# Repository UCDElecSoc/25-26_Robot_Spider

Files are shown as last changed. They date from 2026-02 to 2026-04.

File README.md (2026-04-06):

🕷️ Spider Bot: "LOOK MA, IM JUST LIKE SPIDERMAN!"

Sprider Bot is an open-source, 3D-printed hexapod robot. Built on the ESP32 platform, it features 24 servos and supports remote control via Bluetooth/Radio with a built in camera.

🎥 [Pics](https://github.com/UCDElecSoc/25-26_Robot_Spider/tree/main/Media) | 📁 [Download STL Files](https://github.com/UCDElecSoc/25-26_Robot_Spider/tree/main/Spider%20STLs) | 📖 [Read code](https://github.com/UCDElecSoc/25-26_Robot_Spider/tree/main/Spider_Robot)

🚀 Key Features

24 Servos: 3 joints per leg (Coxa, Femur, Tibia) for fluid, spider-like motion.

A camera: to break several international privacy laws

Spider like motion: to terrorise arachnophobes

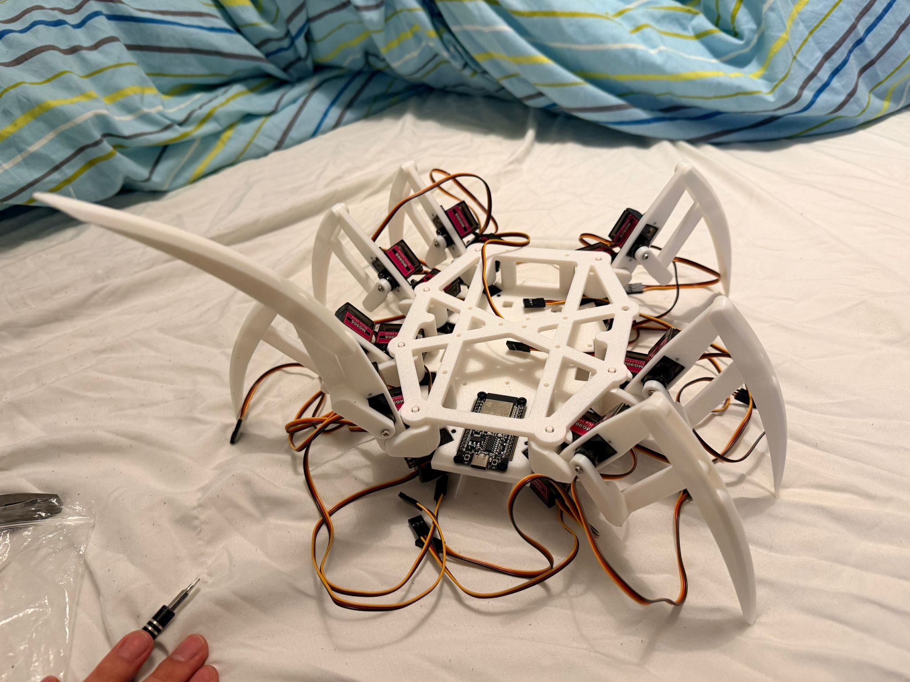
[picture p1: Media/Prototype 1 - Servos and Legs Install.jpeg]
Prototype 1 Image


🛠️ Hardware Requirements

| Component | Quantity | Description |
| :--- | :--- | :--- |
| **Microcontroller** | 1 | ESP32 S3 with Camera |
| **Servo Motors** | 24 | MG90S (Metal Gear) |
| **Servo Driver** | 2 | PCA9685 16-Channel PWM Driver |
| **Power Supply** | 4 | 18650 Cell Battery |
| **Power Regulator** | 1 | 3A 5V BEC |
| **Body** | 1 | 3D Printed Chassis (PETG) |

Open your browser to http://172.20.10.11/ to access the camera, change the password for your own hotspot.
Connect a BTLE or BLE controller to the ESP32 to control the robot

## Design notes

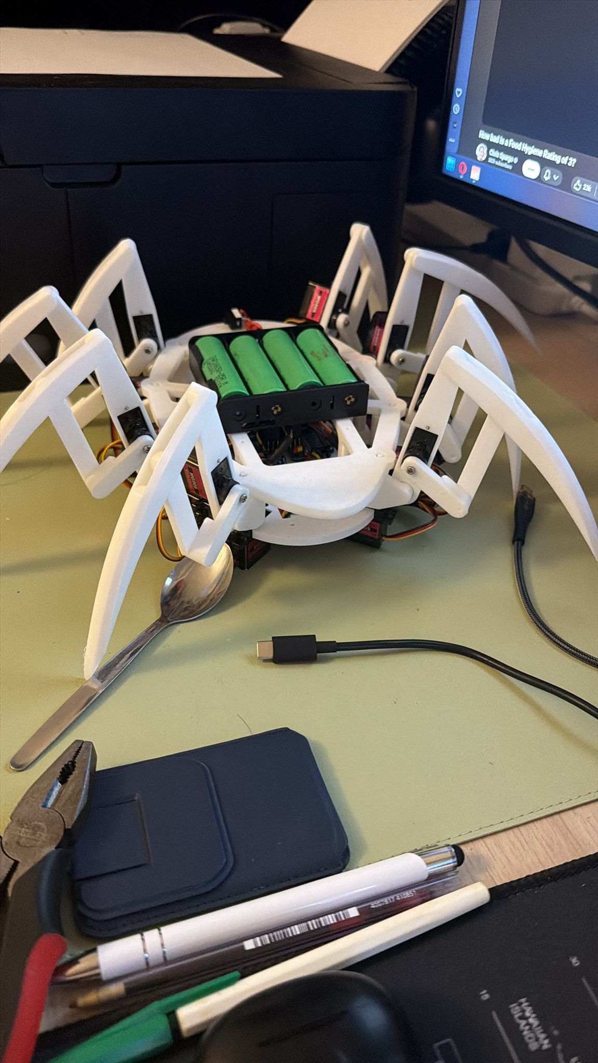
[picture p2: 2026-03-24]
Media/Final Design- Coding time!.jpeg

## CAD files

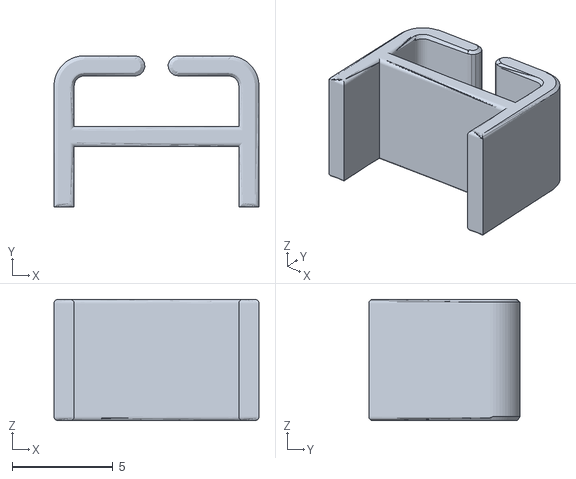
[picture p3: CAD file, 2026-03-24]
Spider STLs/Misc - Cable Clip.stl
10.2 x 7.50 x 6.00

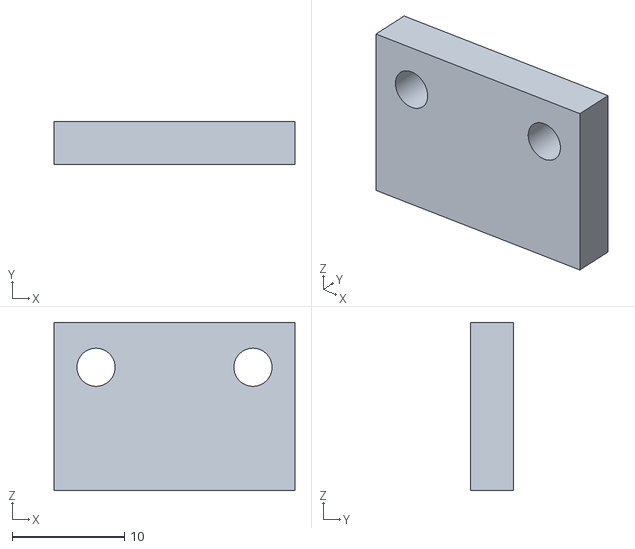
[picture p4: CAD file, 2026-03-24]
Spider STLs/Misc - Camera Esp Holder.stl
21.5 x 3.80 x 15.0

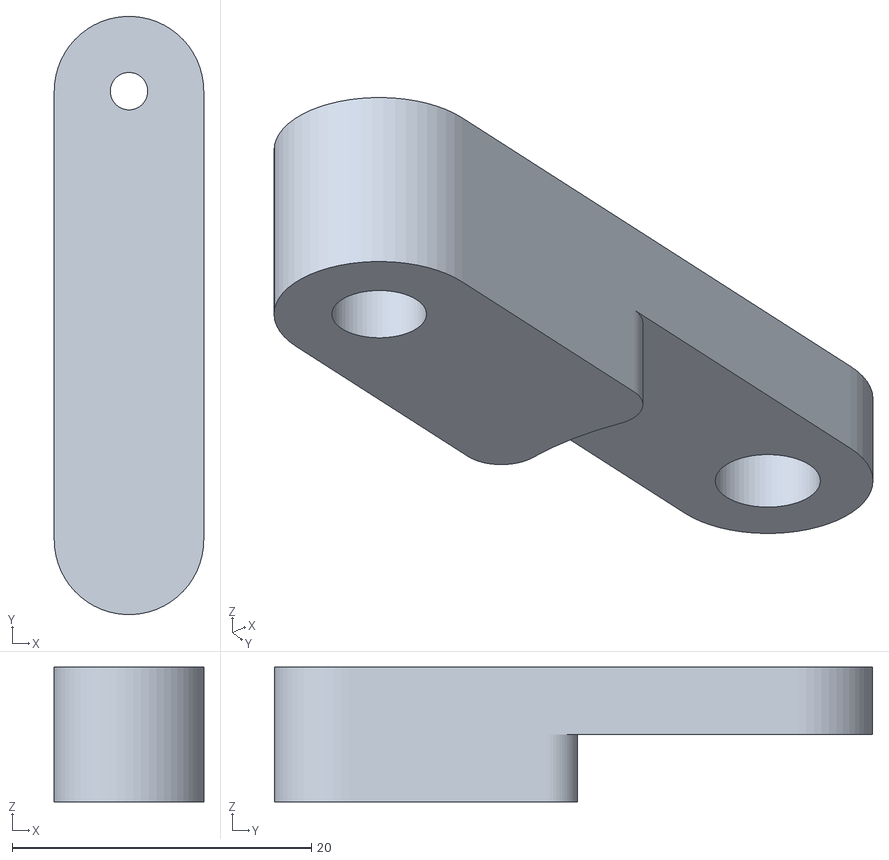
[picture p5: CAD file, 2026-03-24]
Spider STLs/Leg - Short Arm.stl
10.0 x 40.0 x 9.00

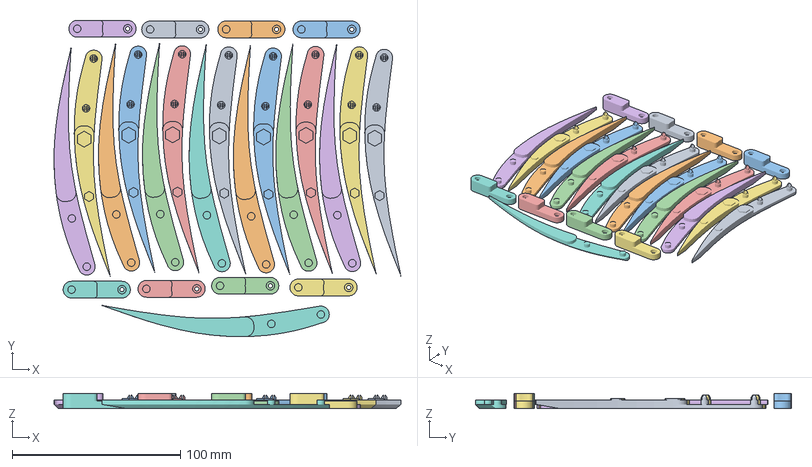
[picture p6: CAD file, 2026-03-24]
Spider STLs/RePrint.3mf
206.5 x 188.3 x 9.00 mm
Leg - Short Arm.stl x 8
Leg - Leg.stl x 16

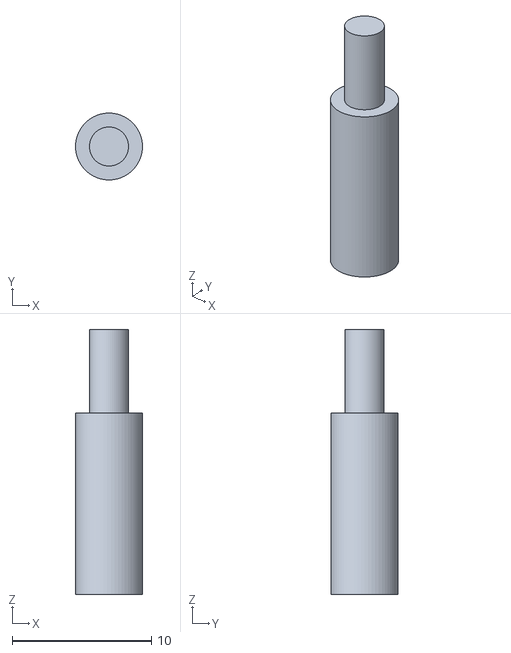
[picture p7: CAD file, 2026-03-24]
Spider STLs/Leg - Base Plug.stl
4.80 x 4.79 x 19.0

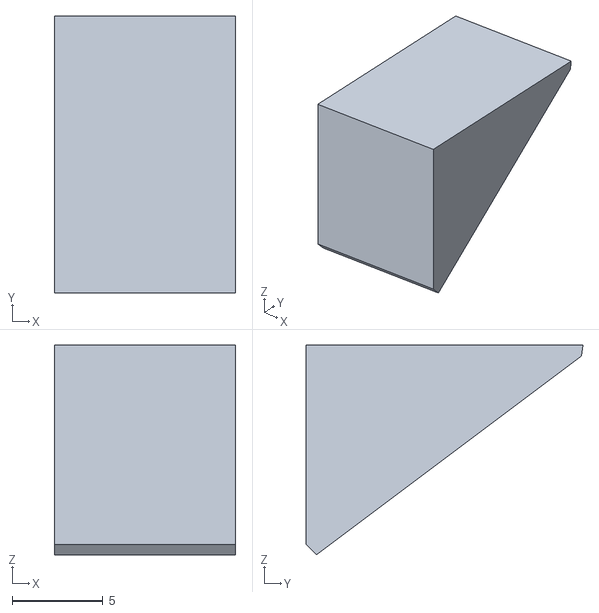
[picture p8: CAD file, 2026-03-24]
Spider STLs/Misc - Camera Stand.stl
10.0 x 15.3 x 11.6

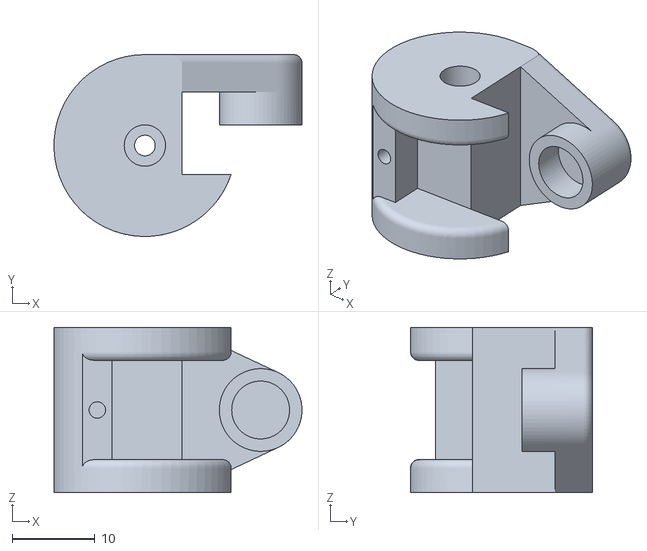
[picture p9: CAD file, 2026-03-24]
Spider STLs/Leg - Base.stl
30.0 x 22.0 x 20.0

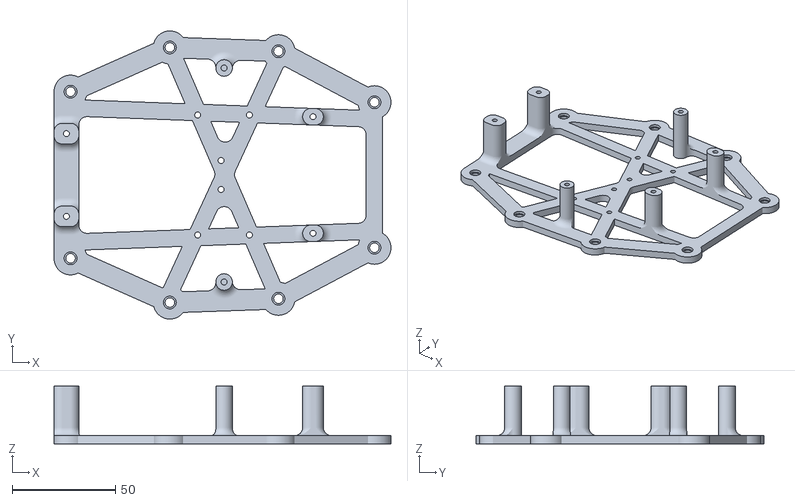
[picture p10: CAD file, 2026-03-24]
Spider STLs/Body - Upper Frame.stl
162.9 x 139.3 x 28.0

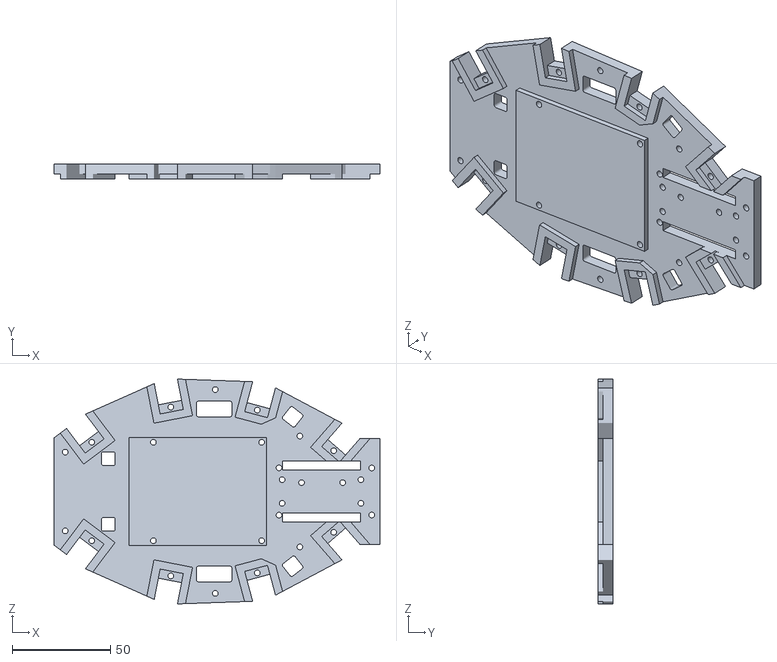
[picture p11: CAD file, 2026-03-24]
Spider STLs/Body - Lower Frame.stl
165.6 x 7.50 x 114.2

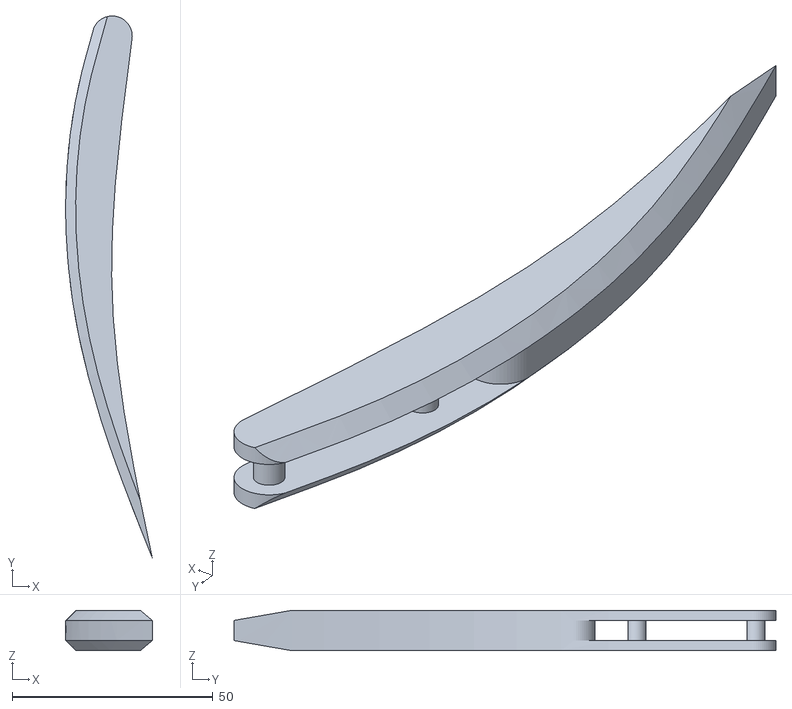
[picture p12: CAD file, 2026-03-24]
Spider STLs/Leg - Leg.stl
21.6 x 135.0 x 10.0

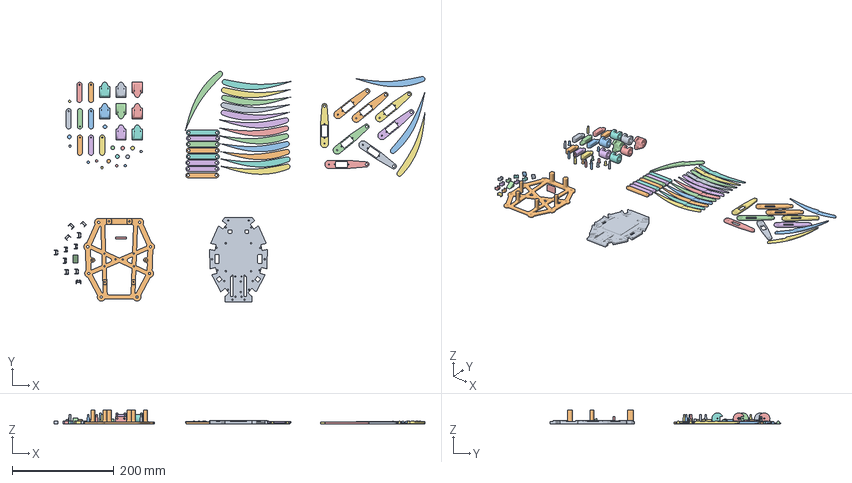
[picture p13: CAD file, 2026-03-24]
Spider STLs/Spider Print.3mf
729.8 x 453.6 x 28.0 mm
Body - Lower Frame.stl
Body - Upper Frame.stl
Leg - Leg.stl x 16
Misc - Camera Stand.stl
Leg - Base.stl x 8
Misc - Cable Clip.stl x 11
Leg - Thigh.stl x 8
Leg - Short Arm.stl x 8
Leg - Short Arm Plug.stl x 8
Leg - Long Arm.stl x 8
Leg - Base Plug.stl x 8
Misc - Camera Esp Holder.stl

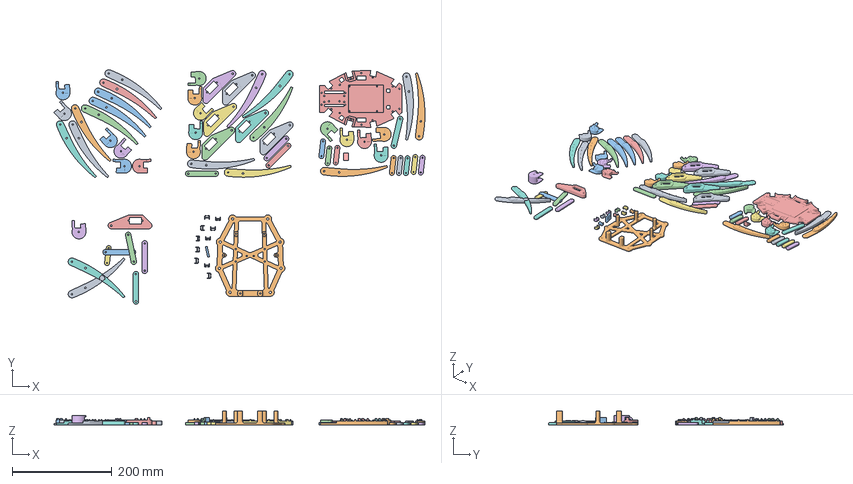
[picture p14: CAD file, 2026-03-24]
Spider STLs/this.3mf
742.4 x 469.3 x 28.0 mm
Spider Leg 0611 - Lower Leg.stl x 16
reinforcementï¼_ bearing frame-2.stl
body concept parts - camera esp stand.stl
Spider Leg 0611 - Lower Beam.stl x 8
body concept parts - Cable clip.stl x 10
body concept parts - body.stl
Spider Leg 0611 - Leg Base.stl x 16
Spider Leg 0611 - Upper Leg.stl x 7
body concept parts - camera stand.stl
Spider Leg 0611 - Upper Beam - Upper Beam.stl x 8
Leg - Leg Base.stl
Leg - Upper Beam.stl
Leg - Lower Leg.stl x 2

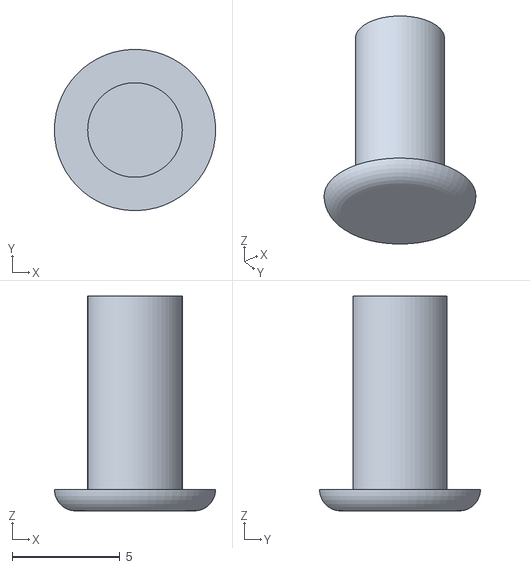
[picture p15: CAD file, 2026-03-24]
Spider STLs/Leg - Short Arm Plug.stl
7.50 x 7.49 x 10.0

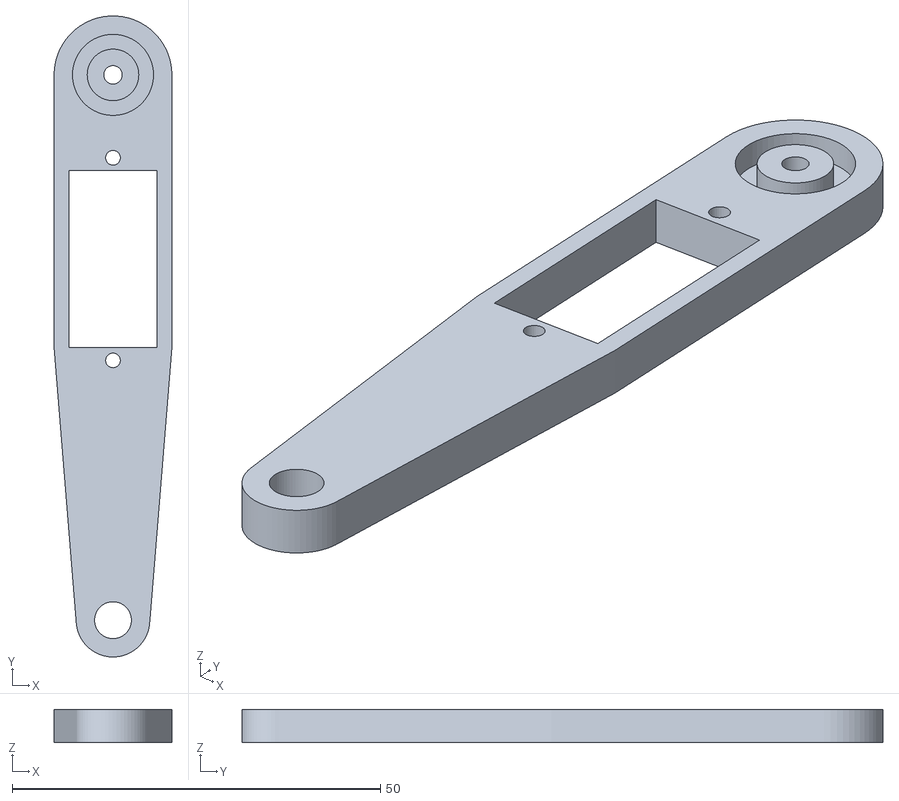
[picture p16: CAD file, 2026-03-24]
Spider STLs/Leg - Thigh.stl
16.0 x 87.0 x 4.50

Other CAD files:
Spider STLs/Leg - Long Arm.stl
Spider STLs/Old Leg/Leg - Upper Leg.stl
Spider STLs/Old Leg/Leg - Upper Beam.stl
Spider STLs/Old Leg/Leg - Lower Beam.stl
Spider STLs/Old Leg/Leg - Leg Base.stl
Spider STLs/Old Leg/Leg - Lower Leg.stl

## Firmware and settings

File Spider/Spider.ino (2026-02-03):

#include <Wire.h>
#include <Adafruit_PWMServoDriver.h>

// Create two PCA9685 objects with different I2C addresses
Adafruit_PWMServoDriver pca1 = Adafruit_PWMServoDriver(0x40);  // Default address
Adafruit_PWMServoDriver pca2 = Adafruit_PWMServoDriver(0x60);  // Alternate address
//hello
// Servo configuration
#define SERVOMIN  100  // Minimum pulse length count (out of 4096)
#define SERVOMAX  500  // Maximum pulse length count (out of 4096)
#define SERVO_FREQ 50  // Analog servos run at ~50 Hz updates

// Number of servos on each board (0-15 for each PCA9685)
#define SERVOS_PER_BOARD 16

void setup() {
  Serial.begin(9600);
  Serial.println("Initializing PCA9685 boards...");

  // Initialize I2C (ESP32 default pins: SDA=21, SCL=22)
  Wire.begin();
  
  // Initialize both PCA9685 boards
  pca1.begin();
  pca1.setPWMFreq(SERVO_FREQ);
  
  pca2.begin();
  pca2.setPWMFreq(SERVO_FREQ);
  
  Serial.println("PCA9685 boards initialized!");
  delay(1000);
}

void moveAllServosToAngle(int angle) {
  // Convert angle (0-180 degrees) to pulse width
  uint16_t pulse = map(angle, 0, 180, SERVOMIN, SERVOMAX);
  
  Serial.print("Moving all servos to angle: ");
  Serial.print(angle);
  Serial.print(" (Pulse: ");
  Serial.print(pulse);
  Serial.println(")");
  
  // Move all servos on PCA9685 #1 (0-15)
  for (int servoNum = 0; servoNum < SERVOS_PER_BOARD; servoNum++) {
    pca1.setPWM(servoNum, 0, pulse);
  }
  
  // Move all servos on PCA9685 #2 (0-15)
  for (int servoNum = 0; servoNum < SERVOS_PER_BOARD; servoNum++) {
    pca2.setPWM(servoNum, 0, pulse);
  }
}

void sweepAllServos() {
  Serial.println("Sweeping all servos from 0 to 180 degrees...");
  
  for (int angle = 0; angle <= 180; angle += 10) {
    moveAllServosToAngle(angle);
    delay(100);
  }
  
  for (int angle = 180; angle >= 0; angle -= 10) {
    moveAllServosToAngle(angle);
    delay(100);
  }
}

void moveIndividualServo(int board, int servoNum, int angle) {
  if (servoNum < 0 || servoNum >= SERVOS_PER_BOARD) {
    Serial.println("Invalid servo number (0-15)");
    return;
  }
  
  uint16_t pulse = map(angle, 0, 180, SERVOMIN, SERVOMAX);
  
  if (board == 1) {
    pca1.setPWM(servoNum, 0, pulse);
    Serial.print("Board 1, Servo ");
  } else if (board == 2) {
    pca2.setPWM(servoNum, 0, pulse);
    Serial.print("Board 2, Servo ");
  } else {
    Serial.println("Invalid board number (1 or 2)");
    return;
  }
  
  Serial.print(servoNum);
  Serial.print(" to angle: ");
  Serial.println(angle);
}

void loop() {
  // Example 1: Move all servos together
  Serial.println("\n--- Example 1: All servos to 90 degrees ---");
  moveAllServosToAngle(90);
  delay(2000);
  
  // Example 2: Sweep all servos
  Serial.println("\n--- Example 2: Sweeping all servos ---");
  sweepAllServos();
  delay(2000);
  
  // Example 3: Move individual servos
  Serial.println("\n--- Example 3: Moving individual servos ---");
  
  // Move servo 0 on both boards
  moveIndividualServo(1, 0, 0);
  moveIndividualServo(2, 0, 180);
  delay(1000);
  
  moveIndividualServo(1, 0, 180);
  moveIndividualServo(2, 0, 0);
  delay(1000);
  
  // Wave pattern across servos
  Serial.println("\n--- Example 4: Wave pattern ---");
  for (int i = 0; i < SERVOS_PER_BOARD; i++) {
    moveIndividualServo(1, i, 90 + 90 * sin(i * 0.5));
    moveIndividualServo(2, i, 90 + 90 * cos(i * 0.5));
    delay(100);
  }
  
  delay(2000);
}

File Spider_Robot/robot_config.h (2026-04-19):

#ifndef ROBOT_CONFIG_H
#define ROBOT_CONFIG_H

#include <Arduino.h>
#include <Wire.h>
#include <Adafruit_PWMServoDriver.h>
#include <Bluepad32.h>

// --- Defines ---
#define CAMERA_MODEL_ESP32S3_EYE
#define I2C_SDA 21
#define I2C_SCL 47

#define SERVOMIN  100  
#define SERVOMAX  500  
#define SERVOMID  300  
#define SERVO_FREQ 50  
#define SERVOS_PER_BOARD 16

// --- Structures ---
struct Angle {
    int forward = 30;
    int backward = 30;
    int up = 30;
    int down = 30;
    int in = 20;
    int out = 20;
};

struct LegConfig {
    int rotationPin;
    int upDownPin;
    int inOutPin;
    int portStarbound; 
};

// --- Extern Variables ---
extern Angle angle;
extern LegConfig legs[8];
extern int state;
extern Adafruit_PWMServoDriver pca1;
extern Adafruit_PWMServoDriver pca2;
extern const char* ssid;
extern const char* password;

// --- Function Prototypes ---
void cameraInit(void);
void startCameraServer();
void scanI2C(void);
void calibrate(void);
void setServoAngle(Adafruit_PWMServoDriver &pca, int servoNum, int angle);
void setupServos(void);
void setupCamera(void);
void Ready(void);
void setState(int legIndex, int st, int command);
void walk(int direction);
void waveLeg(int legTarget);
void rippleWave();
void kickLeg(int legTarget);
void onConnectedController(ControllerPtr ctl);
void onDisconnectedController(ControllerPtr ctl);
void processGamepad(ControllerPtr ctl);

#endif // ROBOT_CONFIG_H

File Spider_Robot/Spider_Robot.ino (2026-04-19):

/**********************************************************************
  Project Code      : Robot Spider
  Head Programmers  : Kelvin Gao, Colm McDermott
  Contributers      : Mark Tomas, Nick Fu, UCD ElecSoc Members

  Head of Mech      : Liam Scott
  Contributers      : Li You, Zaid Niaz, UCD ElecSoc Members
***********************************************************************
  Live Video Link   : http://172.20.10.11
  Enter pairing mode on a valid BLE controller to connect

  Please note, only either video or bluetooth works, NOT both
***********************************************************************
  Controller Commands:
  D-Pad             : Movement + Rotation
  A                 : Wave Right
  B                 : Wave Left
  X                 : Readjust Legs
  R-Trigger         : Right Kick
  L-Trigger         : Left Kick
**********************************************************************/

#include "robot_config.h" 

#include "esp_camera.h"
#include <WiFi.h>
#include "sd_read_write.h"
#include "camera_pins.h"

// Connect a Hotspot to use the wifi camera
const char* ssid     = "[insert ur ssid]";   
const char* password = "[insert ur hotspot password]";   

// --- Variable Definitions ---
// Actually create the objects and variables in memory here

Adafruit_PWMServoDriver pca1 = Adafruit_PWMServoDriver(0x40);
Adafruit_PWMServoDriver pca2 = Adafruit_PWMServoDriver(0x60);

ControllerPtr myControllers[BP32_MAX_GAMEPADS];
Angle angle; 

int state = 0;
// Legs from port anitclockwise: 0,1,2,3,4,5,6,7
// Diagram:
//   3  2  1  0
//          --> face
//   4  5  6  7  

LegConfig legs[8] = {  // Leg Pins Config (1 = Port, -1 = Starboard)
    {1,  2,  3,   1},  // Leg 0 [Rot Pin, Up/Down Pin, In/Out Pin, Port(1)]
    {5,  6,  7,   1},  // Leg 1
    {9, 10, 11,  1},  // Leg 2
    {13, 14, 15,  1},  // Leg 3
    {20, 19, 18, -1},  // Leg 4 [Rot Pin, Up/Down Pin, In/Out Pin, Starboard(-1)]
    {23, 22, 21, -1},  // Leg 5
    {28, 27, 26, -1},  // Leg 6
    {32, 31, 30, -1}   // Leg 7
};

void setup() {
  Serial.begin(115200);
  delay(1000);

  // Bluetooth Stuff (COMMENT TO USE CAMERA)
  BP32.setup(&onConnectedController, &onDisconnectedController);
  BP32.forgetBluetoothKeys(); 

//setupCamera();  //UNCOMMENT FOR CAMERA

  setupServos();
  delay(1000);
}

void loop() {
  // Print the current state to the computer
  Serial.print("Executing State: ");
  Serial.println(state + 1); 
  
  //Bluetooth Gamepad check (COMMENT FOR CAMERA)
  BP32.update();
  for (int i = 0; i < BP32_MAX_GAMEPADS; i++) {
    if (myControllers[i] && myControllers[i]->isConnected()) {
        processGamepad(myControllers[i]);
    }
  }
}

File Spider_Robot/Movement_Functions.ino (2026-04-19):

void Ready() {
  state = 0; 
    for (int i = 0; i < 8; i++) {
        setState(i, state, 1);
    }
}

/***********************************************/
/* Walk cycle code                             */
/***********************************************/
void walk(int command) {
    state += 1; 
    
    // Wrap around for the 8-step cycle
    if (state > 8) {
        state = 1; 
    }

    // Pass both the state AND the command down to the legs
    for (int i = 0; i < 8; i++) {
        setState(i, state, command); 
    }
}

void waveLeg(int legTarget) {
    // 1. Stand in the idle position first so the robot is balanced
    Ready();
    delay(200); 

    // 2. Grab the specific leg's hardware config so we know its pins
    LegConfig leg = legs[legTarget];

    // 3. Calculate the lifted and sweep positions using your portStarbound math
    int liftUpDown = 90 + (80 * leg.portStarbound);
    int liftInOut  = 90 + (45 * leg.portStarbound);
    int waveForward = 90 - (40 * leg.portStarbound);
    int waveBack    = 90 + (40 * leg.portStarbound);

    // 4. Lift the leg into the air directly using setServoAngle
    setServoAngle(leg.upDownPin, liftUpDown);
    setServoAngle(leg.inOutPin, liftInOut);
    delay(200);

    // 5. Wave it back and forth 3 times
    for (int i = 0; i < 3; i++) {
        setServoAngle(leg.rotationPin, waveForward);
        delay(150);
        
        setServoAngle(leg.rotationPin, waveBack);
        delay(150);
    }
    // 6. Put the leg back down and return to the normal stance
    Ready();
}

void rippleWave() {
    // 1. Plant all feet firmly on the ground first
    Ready();
    delay(200); 

    // 2. Loop through all 8 legs (Indices 0 through 7)
    for (int i = 0; i < 8; i++) {
        LegConfig leg = legs[i];

        int liftUpDown = 90 + (80 * leg.portStarbound); 
        int liftInOut  = 90 - (45 * leg.portStarbound); 
        
        int downUpDown = 90 + (45 * leg.portStarbound);
        int downInOut  = 90 - (30 * leg.portStarbound);

        setServoAngle(leg.upDownPin, liftUpDown);
        setServoAngle(leg.inOutPin, liftInOut);
        
        delay(200);

        setServoAngle(leg.upDownPin, downUpDown);
        setServoAngle(leg.inOutPin, downInOut);
    }

    // 3. Ensure everything is perfectly aligned at the end
    Ready();
}

void kickLeg(int legTarget) {
    // 1. Brace for the kick
    Ready();
    delay(100); 

    LegConfig leg = legs[legTarget];

    // 2. Calculate the forward rotation
    int kickRot = 90 - (45 * leg.portStarbound); 

    // 3. Determine the Outward Kick Angle based on which leg is kicking
    int kickInOut;
    if (legTarget == 3) {
        kickInOut = 135;
    } else {
        kickInOut = 45;
    }

    // 4. kick
    setServoAngle(leg.rotationPin, kickRot);
    setServoAngle(leg.inOutPin, kickInOut); 
    delay(300); 
    Ready();
}


void setState(int legIndex, int st, int command) {
    LegConfig leg = legs[legIndex]; 

    // Determine Thrust Direction
    int legDirection = 1; 
    if (command == 1) legDirection = 1;
    else if (command == -1) legDirection = -1;
    else if (command == 2) legDirection = leg.portStarbound;
    else if (command == -2) legDirection = -leg.portStarbound;

    // Pre-calculate positions
    int downUpDown = 90 + (45 * leg.portStarbound); 
    int downInOut  = 90 - (30 * leg.portStarbound); 
    int upUpDown   = 90 + (80 * leg.portStarbound); 
    int upInOut    = 90 - (45 * leg.portStarbound);

    int rotCenter   = 90;
    int rotForward  = 90 - (25 * leg.portStarbound * legDirection); 
    int rotBackward = 90 + (25 * leg.portStarbound * legDirection); 

    int currentUpDown, currentInOut, currentRot;

    // Apply the Wave Gait
    if (st == 0) {
        // IDLE / BOOTUP
        currentUpDown = downUpDown; 
        currentInOut = downInOut; 
        currentRot = rotCenter;
    } else {
        // 1. Assign each leg to one of 4 pairs. 
        int groupOffset = 0;
        if (legIndex == 0 || legIndex == 5) groupOffset = 0;      // Pair 0 lifts on steps 1 & 2
        else if (legIndex == 2 || legIndex == 7) groupOffset = 2; // Pair 1 lifts on steps 3 & 4
        else if (legIndex == 4 || legIndex == 1) groupOffset = 4; // Pair 2 lifts on steps 5 & 6
        else if (legIndex == 6 || legIndex == 3) groupOffset = 6; // Pair 3 lifts on steps 7 & 8

        // 2. Calculate this specific leg's current animation frame (0 to 7)
        int localStep = (st - 1 - groupOffset + 8) % 8;

        // 3. Execute the frame
        switch (localStep) {
            case 0: // LIFT (In the air, pointing back)
                currentUpDown = upUpDown; currentInOut = upInOut; currentRot = rotBackward; break;
            case 1: // SWING (In the air, pointing forward)
                currentUpDown = upUpDown; currentInOut = upInOut; currentRot = rotForward; break;
            case 2: // PLANT (Hit the ground, pointing forward)
                currentUpDown = downUpDown; currentInOut = downInOut; currentRot = rotForward; break;
            case 3: // PUSH 1
                currentUpDown = downUpDown; currentInOut = downInOut;
                currentRot = rotForward + ((rotBackward - rotForward) * 1 / 5); break;
            case 4: // PUSH 2
                currentUpDown = downUpDown; currentInOut = downInOut;
                currentRot = rotForward + ((rotBackward - rotForward) * 2 / 5); break;
            case 5: // PUSH 3
                currentUpDown = downUpDown; currentInOut = downInOut;
                currentRot = rotForward + ((rotBackward - rotForward) * 3 / 5); break;
            case 6: // PUSH 4
                currentUpDown = downUpDown; currentInOut = downInOut;
                currentRot = rotForward + ((rotBackward - rotForward) * 4 / 5); break;
            case 7: // PUSH 5 (Fully back, ready to lift on next step)
                currentUpDown = downUpDown; currentInOut = downInOut;
                currentRot = rotBackward; break;
        }
    }

    // OFFSETS
    if (legIndex == 7 || legIndex == 0) {
        currentRot += (25 * leg.portStarbound); 
    }    
    if (legIndex == 6 || legIndex == 1) {
        currentRot += (15 * leg.portStarbound); 
    }

    // Send the Commands
    setServoAngle(leg.rotationPin, currentRot);
    setServoAngle(leg.upDownPin, currentUpDown);
    setServoAngle(leg.inOutPin, currentInOut);
}

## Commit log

2026-03-24 3-D printer files
    [Body - Lower Frame.stl, Body - Upper Frame.stl, Leg - Base Plug.stl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]
2026-04-06 Organisation
    Organised the leg code for the walk cycles
2026-04-06 Add Prototype 1 image to README
    Added an image of Prototype 1 to the README.
